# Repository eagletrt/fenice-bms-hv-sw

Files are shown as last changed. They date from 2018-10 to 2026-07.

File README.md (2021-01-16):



# Fenice's High Voltage Battery Management System

This branch contains two projects: mainboard and cellboard.

For guidelines on how this branching system works head over to the [master's branch README](https://github.com/eagletrt/fenice-bms-hv/blob/master/README.md#repo-guidlines).

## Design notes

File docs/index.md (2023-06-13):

# High-Voltage Battery Management System

Battery management is a collection of operations that ensures the safety and efficiency of the battery pack. A basic battery management system should constantly measure cell temperatures and voltages along with the total pack current output and check that each of those values is within specification.\
If anomalies are detected, the battery should be disconnected immediately via the AIRs.
A good battery management system is also able to keep the battery in good operating conditions, with the goal of maintaining the expected efficiency of the powertrain.

The need of collecting a lot of data from all over the pack has dictated a scattered architecture for the BMS: it uses multiple data acquisition boards (cellboards) and a single control board (mainboard).

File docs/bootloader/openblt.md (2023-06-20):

# OpenBLT

[OpenBLT](https://www.feaser.com/openblt/doku.php) is an open source bootloader that can run on any microcontroller and use any type of communication interface to perform **software updates**, without the need of specialized debugger hardware

Both cellboards' and mainboard's bootloaders are derived from [OpenBLT sources](https://github.com/feaser/openblt)

## Mainboard and Cellboard bootloaders

The `openblt_mainboard` and `openblt_cellboard` folders contains the actual code of the bootloader which has to be flashed to the microcontroller in order to be able to load your program via the desired communication protocol

Each project is generated by `STM32CubeMX` except the `BLT` folder which containts all the necessary sources of OpenBLT, that can be found in it's github repository either in the `Target/Source`, `Target/Source/_template` or `Target/Demo/_template/Boot` folders

The whole bootloader configuration happens in the `blt_conf.h` header file, exception made for the `flashLayout[]` variable in `flash.c`, where the flash layout is specified

---

## Flash via CAN procedure

### Building and flashing the bootloader

Being an `STM32CubeMX` projects, building and flashing the bootloader is straightforward.

### Building the firmware

In order to operate with the bootloader you need to **modify the linker file** (`*_FLASH.ld` in the root directory of your project)

In particular you need to change the `FLASH (rx)` line in the `MEMORY` segment:
   - Change the origin address according to what has been specified in the previously mentioned `flash.c` file (eg. `ORIGIN = 0x8004000`)
   - Change the length of the flash memory in order to match with the specified address (eg. `LENGTH = 496K`)

### Preparing the binaries

In order to send the binaries via CAN they have to be converted to the `.srec` format

This can be achieved with this tool: [arkku/srec](https://github.com/arkku/srec)

*Example*:
```bash
bin2srec -a 0x8004000 -i *.bin -o *.srec
```
---

### Flashing the firmware

The last step requires:
1. A device **directly connected** to the CAN, like telemetry's and steering wheel's Raspberries
2. [Can-utils](https://elinux.org/Can-utils) installed in the device
3. [Bootcommander](https://www.feaser.com/openblt/doku.php?id=manual:bootcommander) installed in the device

When everything is ready the project can be flashed by resetting the microcontroller (via an appropriate *CAN message*)
and then sending the program to flash using the **bootcommander** tool, with:
- The `-t` flag set to `xcp_can`
- The selected CAN peripheral (`-d` flag)
- The *baud rate* (`-b` flag)
- The transmission ID (`-tid` flag) and the reception ID (`-rid` flag)
- The **binary executable** converted to the `.srec` format

*Example*:
```bash
cansend can1 005#00 &&
bootcommander -t=xcp_can -d=can1 -b=1000000 -tid=667 -rid=7E1 fenice-bms.srec
```

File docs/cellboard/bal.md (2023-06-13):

# Cell Balancing
The cell balancing operation is mostly done on the cellboards. However, the mainboard has to compute all the cells that need to be discharged. To synchronize cellboards and the mainboard an FSM is defined:

```diagram
stateDiagram-v2
    direction LR
    [*] --> OFF
    OFF --> CMP
    OFF --> OFF
    CMP --> DSC
    CMP --> OFF
    DSC --> COOL
    DSC --> OFF
    DSC --> DSC
    COOL --> CMP
    COOL--> OFF
    COOL --> COOL
```
### - Off (OFF)
The dormant state of the balancing algorithm.

### - Compute (CMP)
Compute phase. This is where the cell selection algorithm is run. If no cells need to be discharged the FSM returns back to the _Off_ state.
The compute phase can be triggered manually via the CLI.

The algorithm is split in two phases:
#### Imbalance computation
The imbalance is the voltage difference between a given cell and the minimum-voltage cell. In this phase an imbalance array that contains the imbalances of every cell is created. In this case the imbalance is centered around the minimum-voltage plus a threshold, that is the maximum imbalance permitted in the pack.

$imbalance[i] = \max(0, voltages[i] −(min\_voltage + threshold))$

#### Cell selection
The cell selection algorithm is very simple: if the imbalance is greater than 0, the cell is selected for discharge

### - Discharge (DSC)
After compute the mainboard sends the list of cells to be discharged to the cellboards that start the actual discharge for a set amount of time. The discharge time depends on configuration but it's in the range from 30 to 120s.

### - Cooldown (COOL)
Cooldown. A small period (5-10s) where voltages are

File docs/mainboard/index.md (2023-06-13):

# Mainboard

**The Mainboard is the central control unit of the BMS**.\
It contains a microcontroller that handles two CAN-bus lines for internal and external communications, peripherals such as insulated *ADCs*, *EEPROMs*, serial ports, an SD-card and more.\
The mainboard is **responsible for the actuation of the AIRs and contains the shutdown and pre-charge circuits**.\
It also communicates voltages, temperatures, currents, battery status, warnings and errors to the rest of the car via CAN-bus. An integrated serial command-line interface and internal logging are included to help with troubleshooting.

The logic of the mainboard is handled by a couple of FSM *<small>(Finite States Machines)</small>*. The [FSM](https://github.com/eagletrt/micro-libs/tree/master/fsm) library is used to manage every state machine of the *BMS*.

---

## Subsystems

There are several subsystems to the mainboard's firmware:

- **[bal](subsystems/bal)**: contains functions of the cell balancing algorithm.
- **[bal_fsm](subsystems/bal)**: contains the balancing algorithm's FSM.
- **[bms_fsm](subsystems/bms_fsm)**: the BMS' FSM handles the main state machine of the board and it's responsible for the management of the tractive system's activation and deactivation.
- **[cli_bms](subsystems/cli_bms)**: all the CLI commands are defined here.
- **[config](subsystems/config)**: generic interface that handles all sorts of configurations.
- **[current](subsystems/current)**: current measurement functions.
- **[energy](subsystems/energy)**: energy measurement and State-of-Charge estimation logic.
- **[feedback](subsystems/feedback)**: mainboard's feedbacks handler functions and variables.
- **[pack](subsystems/pack)**: battery pack hardware control's interface.
- **[soc](subsystems/soc)**: State-of-Charge estimation functions *(at the moment it doesn't work)*.
- **[timebase](subsystems/timebase)**: controls all repeating actions of the firmware.

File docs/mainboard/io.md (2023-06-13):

# I/O

There are many peripherals and devices connected to the mainboard.

Every component that interfaces with the mainboard's microcontroller is listed here:

- **CAN-buses** (CAN):\
    a CAN-bus to communicate with the car and an internal isolated bus for handling the cellboards.
- **adc124021 ADC** (SPI):\
    used to measure pack's and bus' voltages, also used to measure the pack's current using a shunt resistor.
- **DAHB S/160 Hall-effect sensor** (ADC):\
    used to measure pack's current. It's less precise than the shunt, included for historical reasons. The unit contains two sensors with different gains to have a broader current range.
- **AIR and pre-charge controls**:\
    three output pins control the actuation of the AIRs *(if the shutdown circuit is not latched in the off state)* and the pre-charge circuit.
- **Circuit feedbacks** (MUX/ADC):\
    16 multiplexed analog signals coming from the mainboard's circuit. It's used to diagnose the circuit and to verify its correct state compared to the BMS state. Some of those feedbacks are not multiplexed to let them generate of interrupts.
- **IMD Status** (PWM):\
    the IMD has an output PWM signal that reports its internal state.
- **M95256 EEPROM** (SPI):\
    used to store runtime variables and data, such as State-of-Charge information, balancing threshold and more.
- **SD-card** (SPI):\
    an SD-card has been included on the mainboard, in order to use it as storage for extended logs.
- **User console** (UART):\
    a serial interface has been reserved as an user interface to read/write data and execute commands. The [cli](https://github.com/eagletrt/micro-libs/tree/master/cli) library is used as an interface.
- **GPIOs**:\
    9 GPIO pins for external stuff.

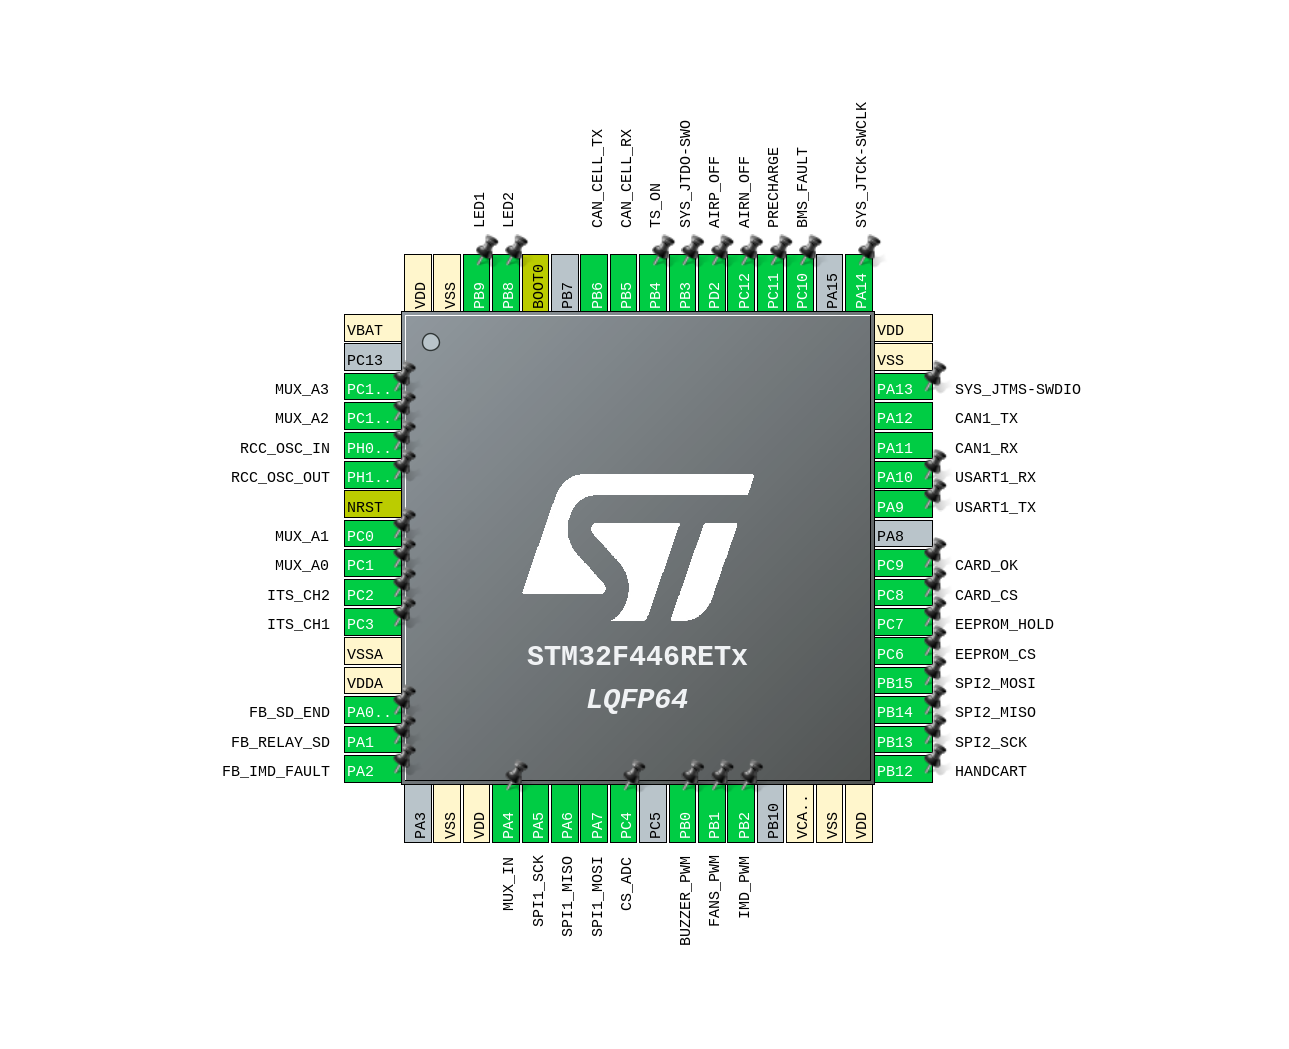
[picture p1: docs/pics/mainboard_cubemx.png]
Mainboard's I/O configuration


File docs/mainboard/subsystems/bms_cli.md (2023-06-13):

# Command Line Interface

The command line interface of the Mainboard is based on the [cli](https://github.com/eagletrt/micro-libs/tree/master/cli) library. It serves as the main interface with the BMS. The CLI is clocked at 115200 baud and uses local echo

!!! warning
	The CLI runs on UART1, thus it is not compatible with STM32 Nucleo boards that normally use UART2 as the USB serial console.

As the name implies, the CLI is based around commands, in a style inspired by Unix consoles. Pressing `?` followed by `Enter` will give a list of legal commands.

## Commands
### `volt`
The `volt` command returns the main voltages of the battery pack.

!!! example
	```
	bus.......0.00 V
	internal..388.8 V
	average...3.60 V
	max.......3.70 V
	min.......3.50 V
	delta.....0.20 V
	```

#### Parameters
- `all`: prints all cell voltages (plus some usefull information about balancing).

### `temp`
Similarly to the `volt` command, `temp` will return the main temperatures of the pack.
#### Parameters
- `all`: Prints all battery temperatures.

### `status`
Returns a summary of the general status of the BMS.

### `errors`
This command will return a list containing each active errors and its details

### `ts`
Controls the Tractive System actuation.
#### Parameters
- `on`: generates a `TS_ON` event on the [BMS FSM](../bms_fsm).
- `off`: triggers `TS_OFF` event on the aforementioned FSM.

### `bal`
Suite of commands that handle the balancing process.
#### Parameters
- `on`: Triggers an event that enables the [BAL FSM](../bal_fsm).
- `off`: Triggers an event that disables balancing.
- `thr`: Returns the currently set threshold.
- `thr <millivolts>`: Sets the threshold to the value of `<millivolts>`.
    Please be gentle with it: it can break bad if you input strange stuff
- `test <board> <cell0 cell1 ... cellN>`: starts a balancing cycle in the `board` on the specified cells

### `soc`
Return state of charge information
#### Parameters
- `reset`: resets the 'last charge' energy meter.

### `current`
Shows current measurement for all the available sensors.
#### Parameters
- `zero`: zeroes the Hall-effect sensors.

### `dmesg`
Toggles the debug output. This can be quite verbose if enabled.

### `reset`
Resets the microcontroller. Analogue to pressing the reset button on board.

### `imd`
Show imd details

### `feedbacks`
Show feedbacks status

### `watch`
Repeatedly run a command
#### Parameters
- `<interval ms> <cmd>`

### `cell_distr`
Lets you change the cellboard arrangment into the pork
#### Parameters
- ``: Show current cellboard distribution
- `<cell0> ... <cellN>`: Update cellboard distribution

### `fans`
Control the pork fans
#### Parameters
- `off`: shut down fans
- `<0-100>`: sets fans power

### `pack`
Control low level ts hardware
!!! warning
	This can lead to dangerous behaviours when the tractive system is connected, be carefull
#### Parameters
- `airn <on/off>`: controls the air negative
- `airp <on/off>`: controls the air positive
- `precharge <on/off>`: controls the precharge relay

### Easter eggs?
Of course

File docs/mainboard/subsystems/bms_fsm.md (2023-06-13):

# Main State Machine
The BMS fsm handles the main state machine of the board. It is responsible for the management of the tractive system activation and deactivation.

# States
```diagram
stateDiagram-v2
    direction LR
    [*] --> Idle
    Idle --> AirnClose
    Idle --> Error
    AirnClose --> Idle
    AirnClose --> AirnStatus
    AirnClose --> Error
    AirnStatus --> Precharge
    AirnStatus --> Idle
    AirnStatus --> Error
    Precharge --> On
    Precharge --> Idle
    Precharge --> Error
    On --> Idle
    On --> Error
    Error --> Idle
```

## - **Idle**
When the TS is off and no fatal errors are present, the BMS is in the Idle state.

## - **AirnClose**
When the procedure of activation of the Tractive System is requested. Additional feedbacks are checked in order to close the AIR negative.

## - **AirnStatus**
Checks if the activation of the AIR negative is ok.

## - **Precharge**
The Precharge procedure is done to turn on the Tractive System. It involves the actuation of the precharge relay and the monitoring of the bus voltage.
The bus voltage is periodically confronted with the internal voltage and when they are within 7% of each other the positive AIR is closed and the precharge relay is opened, ending the precharge procedure. The FSM then transitions to the TS_On state. If the bus voltage doesn't rise fast enough, the precharge fails and the FSM goes back to Idle.

## - **TS_On**
In this state the high-voltage bus external to the battery is powered. This is the state in which the car can run, or the battery can be charged.
When the TS_OFF event occurs, the FSM transitions back to Idle, opening both AIRs at the same time.

## - **Error**
If a fatal error is active the BMS is in this state. TS activation requests are ignored. If every fatal error expires, then the BMS returns to Idle and can accept TS on commands again.

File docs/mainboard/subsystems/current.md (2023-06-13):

# Current
Current measurements involves 2 different sensors, the shunt resistor, measured through the isolated ADC and the 2-channel analog Hall sensor, sampled through internal ADCs.

### Current zeroing
All the 3 measures involve offsets, which are calculated in those situations where the current is 0 (when both AIRs and precharge relay are open).

### Shunt resistor
The value coming from the ADC is converted with this formula: `(volt - shunt_offset) / (1e-4f * 500)`

### Hall Sensor
#### High channel
The analog signal is read by adc2 in DMA mode in a 128 items array. When the current need to be retrieved, those values are averaged. The value is converted with this formula: `(499.f / 300.f / 6.67e-3f) * (volt - high_channel_offset)`

#### Low channel
The analog signal is read by adc3 in DMA mode in a 128 items array. When the current need to be retrieved, those values are averaged. The value is converted with this formula: `(499.f / 300.f / 40e-3f) * (volt - low_channel_offset)`

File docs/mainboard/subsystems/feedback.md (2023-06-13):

# Feedback
Feedback system is a self check of the car state, used in the [bms_fsm](subsystems/bms_fsm).  
It consists of 19 signals by which is possible to verify the correct behaviour of the fsm and react to changes on the shutdown.
16 of them are multiplexed and 3 are not, in order to react quicker to them.
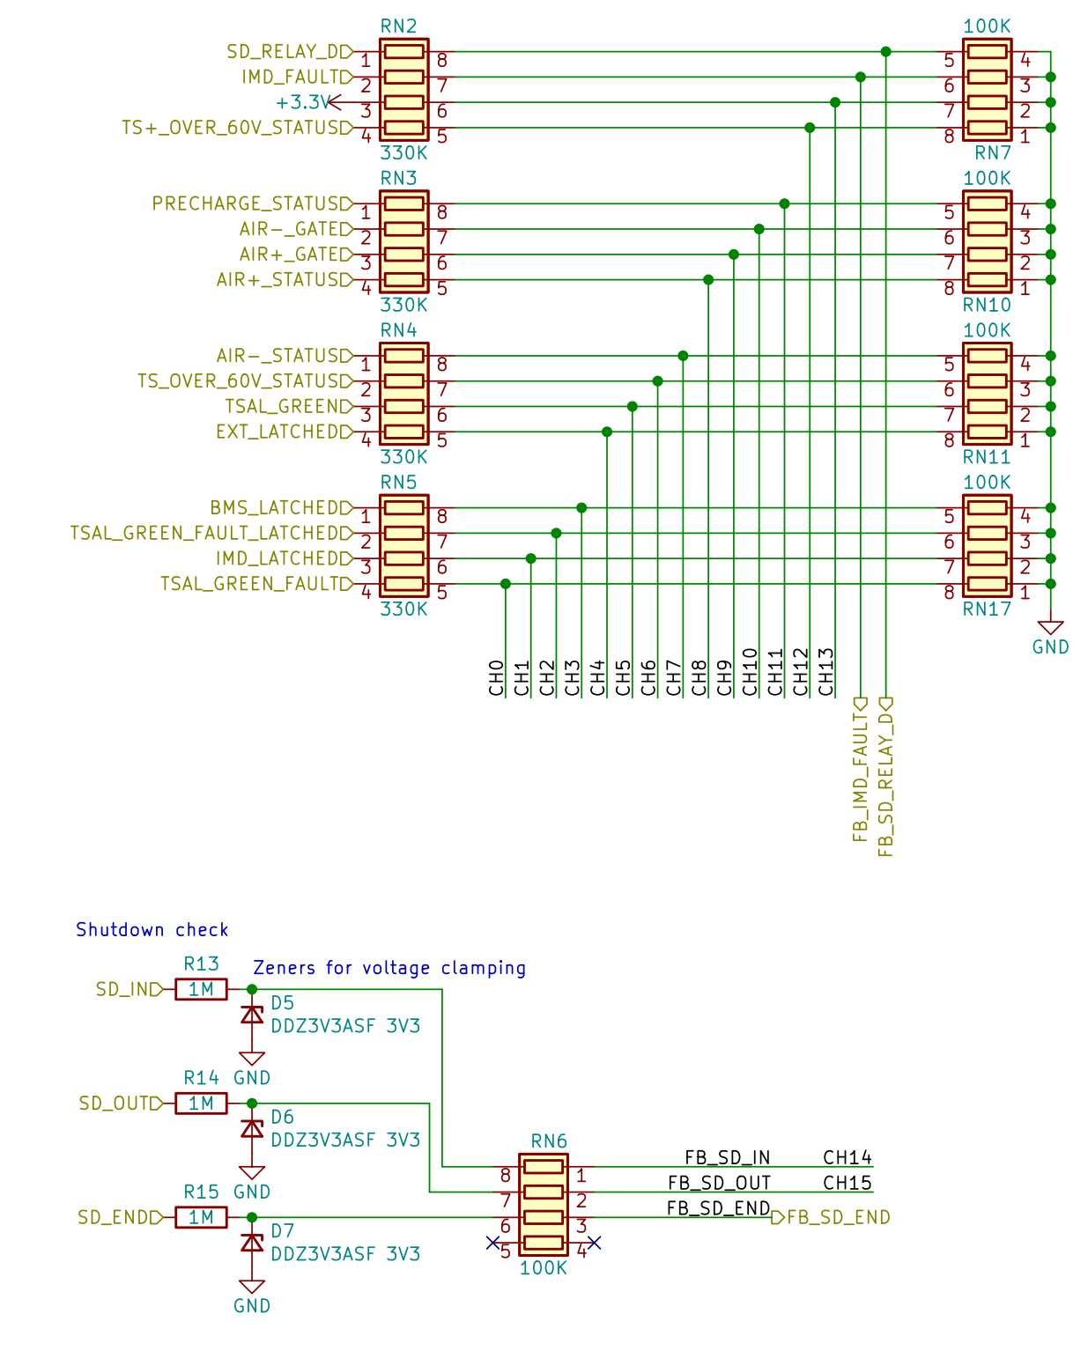
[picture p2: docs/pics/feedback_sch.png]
bms_fsm

All theese signals are read with an internal ADC (adc1) in order to better interprete their logic state (actually if <2.5V is low, >9.5 is high and everything in between is unsafe)

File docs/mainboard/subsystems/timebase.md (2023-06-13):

# Timebase
It sets a timer to tick every 10ms, then sets the respective flag whenever a interval is matched. By calling it's routine function from the main loop is possible to execute the needed code at fixed intervals.
Specifically is used to read voltages, current and temperatures, to send periodic can messages and to control fans.

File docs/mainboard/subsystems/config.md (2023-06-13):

# Config
The config subsystem is a generic configuration manager that handles the storage and retrieval of vairables from an on-board EEPROM, model m95256.
The `config` struct contains all the needed data:
```c
struct config {
    uint32_t version;
    uint16_t address;
    bool dirty;
    size_t size;
    void *data;
};
```
`version` stores a version string that is used during to verify that the read data is right. By changing the version string the data gets automatically overwritten with default values.

The `config` struct is rendered opaque by the use of the `config_t` type. This avoids direct access to `config`'s content.

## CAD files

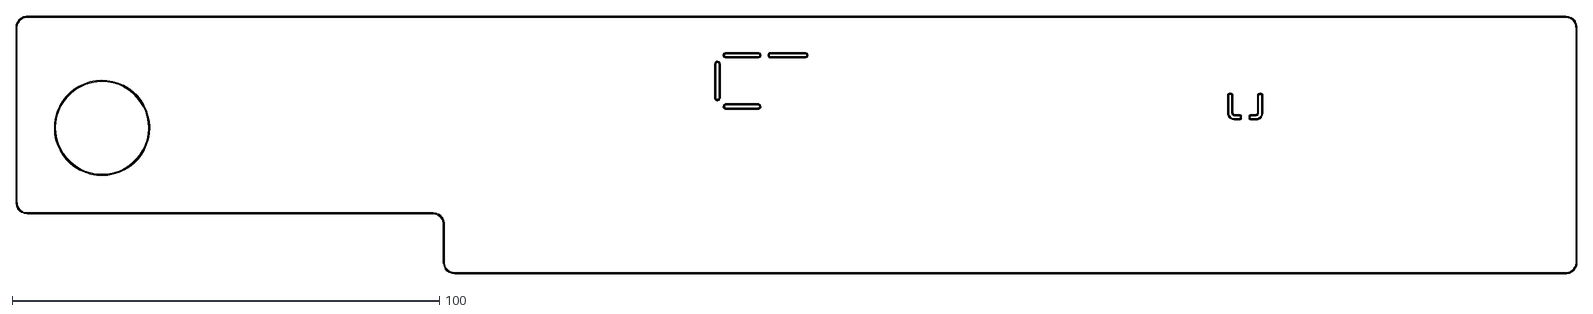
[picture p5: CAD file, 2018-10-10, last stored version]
Schematics/BMS_HV-2017-2018 chimera/BMS_HV/MainBoard/V2/gerber/MainBoard-Edge.Cuts.dxf
365.2 x 60.2

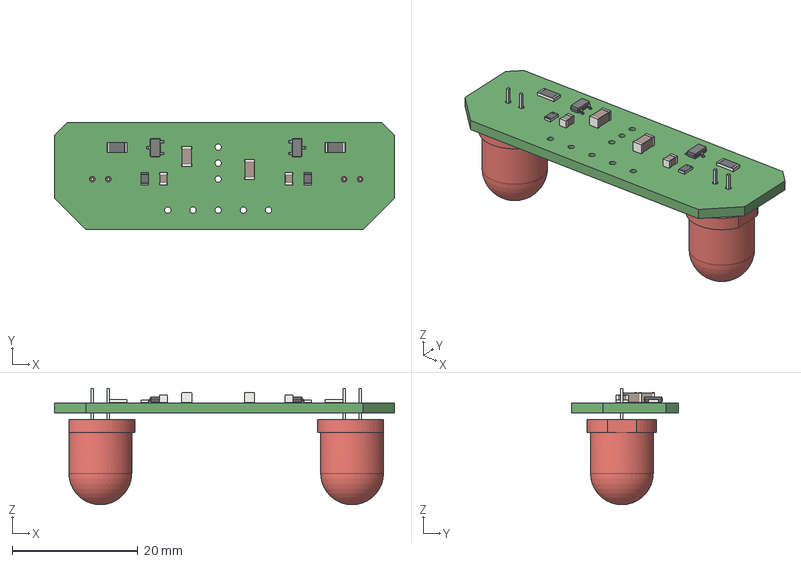
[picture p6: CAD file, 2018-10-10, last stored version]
Schematics/BMS_HV-2017-2018 chimera/BMS_HV/CockpitLED/CockpitLED.stp
54.0 x 17.0 x 18.5 mm

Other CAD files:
Schematics/BMS_HV-2017-2018 chimera/BMS_HV/CockpitLED/Box.ipt
Schematics/BMS_HV-2017-2018 chimera/BMS_HV/CockpitLED/COMPOUND.ipt
Schematics/BMS_HV-2017-2018 chimera/BMS_HV/CockpitLED/C_0805_2012Metric.iam
Schematics/BMS_HV-2017-2018 chimera/BMS_HV/CockpitLED/C_1206_3216Metric.iam
Schematics/BMS_HV-2017-2018 chimera/BMS_HV/CockpitLED/CockpitLED.iam
Schematics/BMS_HV-2017-2018 chimera/BMS_HV/CockpitLED/LED_D10.0mm.iam
Schematics/BMS_HV-2017-2018 chimera/BMS_HV/CockpitLED/OldVersions/Box.0002.ipt
Schematics/BMS_HV-2017-2018 chimera/BMS_HV/CockpitLED/R_0805_2012Metric.iam
Schematics/BMS_HV-2017-2018 chimera/BMS_HV/CockpitLED/R_1206_3216Metric.iam
Schematics/BMS_HV-2017-2018 chimera/BMS_HV/CockpitLED/SOLID.ipt
Schematics/BMS_HV-2017-2018 chimera/BMS_HV/CockpitLED/SOLID_1.ipt
Schematics/BMS_HV-2017-2018 chimera/BMS_HV/CockpitLED/SOLID_2.ipt
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

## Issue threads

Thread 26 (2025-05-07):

Update canlib version

Tonidotpy, 2025-05-07:
# Description

Given the last days problems with the new high voltage battery pack it is needed to put the old battery pack into the car and make it work with the latest versions of the canlib.

## Implementation Steps

1. Pull the latest version of the canlib for both mainboard and cellboard
2. Try to compile both mainboard and cellboard code and see if there is any error
3. Fix errors related to the new version of the canlib

## Additional Notes

All the messages are handled inside the `can_comm.h` file.

Closed 2025-07-02.

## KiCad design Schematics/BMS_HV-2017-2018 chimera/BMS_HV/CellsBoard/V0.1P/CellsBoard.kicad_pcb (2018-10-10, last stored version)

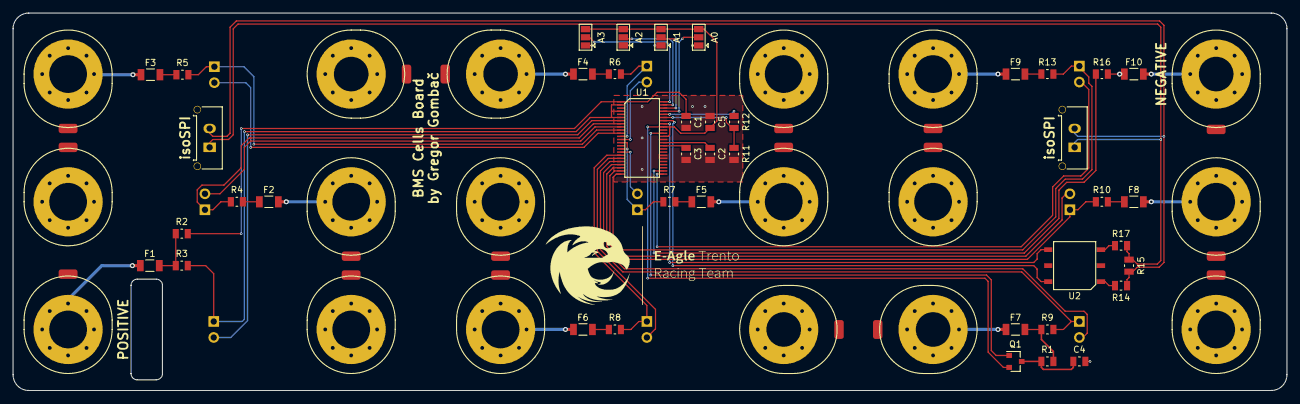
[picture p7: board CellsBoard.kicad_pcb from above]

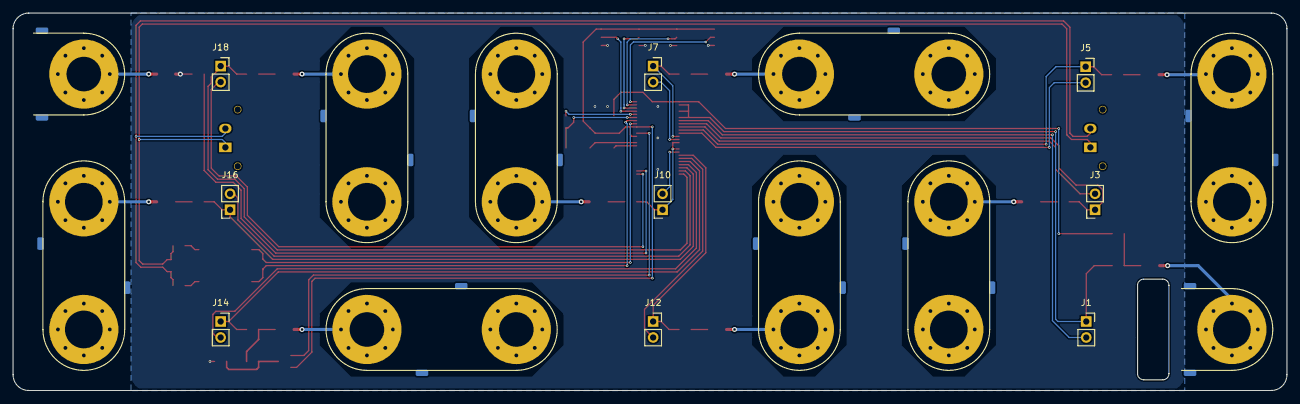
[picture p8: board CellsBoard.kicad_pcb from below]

Board: 2 copper layers, 202.5 x 60.0 mm, 60 parts (9 on the bottom side), 57 nets.

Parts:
C1, C4, C5: 100n; C_0805_2012Metric
C2, C3: 1u; C_0805_2012Metric
F1, F2, F3, F4, F5, F6, F7, F8, F9, F10: Fuse; Fuse_1206_3216Metric
J1: Temp9; PinSocket_1x02_P2.54mm_Vertical
J2: Cell9; CellEndS
J3: Temp8; PinSocket_1x02_P2.54mm_Vertical
J4: Cell8; CellShort
J5: Temp7; PinSocket_1x02_P2.54mm_Vertical
J6: Cell7; CellShort
J7: Temp6; PinSocket_1x02_P2.54mm_Vertical
J8: Cell6; CellLong
J10: Temp5; PinSocket_1x02_P2.54mm_Vertical
J11: Cell5; CellShort
J12: Temp4; PinSocket_1x02_P2.54mm_Vertical
J13: Cell4; CellShort
J14: Temp3; PinSocket_1x02_P2.54mm_Vertical
J15: Cell3; CellLong
J16: Temp2; PinSocket_1x02_P2.54mm_Vertical
J17: Cell2; CellShort
J18: Temp1; PinSocket_1x02_P2.54mm_Vertical
J19: Cell1; CellShort
J20: Cell0; CellEndD
J21, J22: isoSPI; Molex_Micro-Fit_3.0_43650-0215_1x02_P3.00mm_Vertical
JP1: A3; SolderJumper-3_P1.3mm_Open_Pad1.0x1.5mm
JP2: A2; SolderJumper-3_P1.3mm_Open_Pad1.0x1.5mm
JP3: A1; SolderJumper-3_P1.3mm_Open_Pad1.0x1.5mm
JP4: A0; SolderJumper-3_P1.3mm_Open_Pad1.0x1.5mm
Q1: BC846AW; SOT-23
R1, R2: 100R; R_0805_2012Metric
R3, R4, R5, R6, R7, R8, R9, R10, R13, R16: 330R; R_0805_2012Metric
R11: 1K4; R_0805_2012Metric
R12: 604R; R_0805_2012Metric
R14, R17: 22R; R_0805_2012Metric
R15: 120R; R_0805_2012Metric
U1: LTC6804; SSOP-48
U2: HM2103

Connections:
/0V: C1.2, C2.2, C3.2, C4.2, C5.2, F10.2, JP1.1, JP2.1, JP3.1, JP4.1, R11.2, R16.1, U1.30, U1.31, U1.36
/A0: JP4.2, U1.45
/A1: JP3.2, U1.46
/A2: JP2.2, U1.47
/A3: JP1.2, U1.48
/C0: R16.2, U1.26
/C1: J18.1, R13.2, U1.24
/C2: J16.1, R10.2, U1.22
/C3: J14.1, R9.2, U1.20
/C4: J12.1, R8.2, U1.18
/C5: J10.1, R7.2, U1.14, U1.16
/C6: J7.1, R6.2, U1.12
/C7: J5.1, R5.2, U1.10
/C8: J3.1, R4.2, U1.8
/C9: J1.1, R3.2, U1.2, U1.4, U1.6
/CB1: F9.2, R13.1
/CB2: F8.2, R10.1
/CB3: F7.2, R1.1, R9.1
/CB4: F6.2, R8.1
/CB5: F5.2, R7.1
/CB6: F4.2, R6.1
/CB7: F3.2, R5.1
/CB8: F2.2, R4.1
/CB9: F1.2, R2.1, R3.1
/S1: J18.2, U1.25
/S2: J16.2, U1.23
/S3: J14.2, U1.21
/S4: J12.2, U1.19
/S5: J10.2, U1.17
/S6: J7.2, U1.13
/S7: J5.2, U1.11
/S8: J3.2, U1.9
/S9: J1.2, U1.7
/V+: C1.1, R2.2, U1.1
/VRef1: C2.1, U1.35
/VRef2: C3.1, U1.34
/Vreg: C5.1, JP1.3, JP2.3, JP3.3, JP4.3, Q1.2, U1.37, U1.40
/drive: Q1.1, U1.38
unnamed: C4.1, Q1.3, R1.2
unnamed: F1.1, J2.1
unnamed: F2.1, J4.1
unnamed: F3.1, J6.1
unnamed: F4.1, J8.1
unnamed: F5.1, J11.1
unnamed: F6.1, J13.1
unnamed: F7.1, J15.1
unnamed: F8.1, J17.1
unnamed: F9.1, J19.1
unnamed: F10.1, J20.1
unnamed: J21.1, J22.1, R15.2, R17.2
unnamed: J21.2, J22.2, R14.2, R15.1
unnamed: R11.1, R12.2, U1.43
unnamed: R12.1, U1.44
unnamed: R14.1, U2.1
unnamed: R17.1, U2.3
unnamed: U1.41, U2.4
unnamed: U1.42, U2.6

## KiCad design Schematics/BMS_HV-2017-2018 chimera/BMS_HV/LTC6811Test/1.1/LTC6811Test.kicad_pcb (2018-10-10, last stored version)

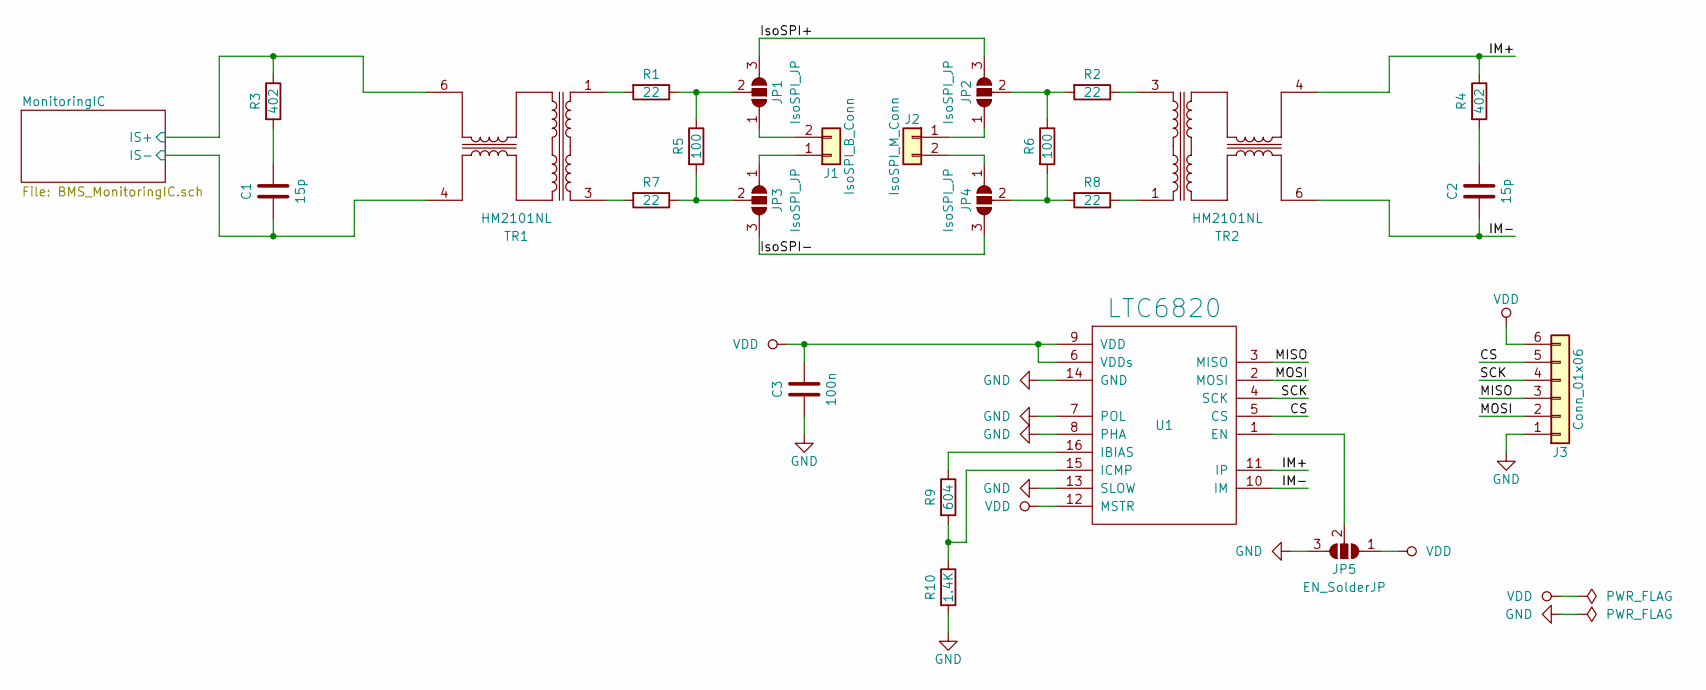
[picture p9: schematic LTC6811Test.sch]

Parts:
C1, C2: 15p; C_0805_2012Metric_Pad1.15x1.50mm_HandSolder
C3: 100n; C_0805_2012Metric_Pad1.15x1.50mm_HandSolder
J1: IsoSPI_B_Conn; PinHeader_1x02_P2.54mm_Vertical
J2: IsoSPI_M_Conn; PinHeader_1x02_P2.54mm_Vertical
J3: Conn_01x06; PinHeader_1x06_P2.54mm_Vertical
JP1, JP2, JP3, JP4: IsoSPI_JP; SolderJumper-3_P1.3mm_Open_Pad1.0x1.5mm
JP5: EN_SolderJP; SolderJumper-3_P1.3mm_Open_Pad1.0x1.5mm
R1, R2, R7, R8: 22; R_0805_2012Metric_Pad1.15x1.50mm_HandSolder
R3, R4: 402; R_0805_2012Metric_Pad1.15x1.50mm_HandSolder
R5, R6: 100; R_0805_2012Metric_Pad1.15x1.50mm_HandSolder
R9: 604; R_0805_2012Metric_Pad1.15x1.50mm_HandSolder
R10: 1.4K; R_0805_2012Metric_Pad1.15x1.50mm_HandSolder
TR1, TR2: HM2101NL
U1: LTC6820; MSOP-16

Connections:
/CS: J3.5, U1.5 (CS)
/IM+: R4.1, TR2.4, U1.11 (IP)
/IM-: C2.1, TR2.6, U1.10 (IM)
/IsoSPI+: JP1.3 (B), JP2.3 (B)
/IsoSPI-: JP3.3 (B), JP4.3 (B)
/MISO: J3.3, U1.3 (MISO)
/MOSI: J3.2, U1.2 (MOSI)
/MonitoringIC/IS+: R3.1, TR1.6; also elsewhere on the board
/MonitoringIC/IS-: C1.1, TR1.4; also elsewhere on the board
/SCK: J3.4, U1.4 (SCK)
GND: C3.2, J3.1, JP5.3 (B), R10.2, U1.7 (POL), U1.8 (PHA), U1.13 (SLOW), U1.14 (GND)
unnamed: C1.2, R3.2
unnamed: C2.2, R4.2
unnamed: J1.1, JP3.1 (A)
unnamed: J1.2, JP1.1 (A)
unnamed: J2.1, JP2.1 (A)
unnamed: J2.2, JP4.1 (A)
unnamed: JP1.2 (C), R1.1, R5.1
unnamed: JP2.2 (C), R2.2, R6.1
unnamed: JP3.2 (C), R5.2, R7.1
unnamed: JP4.2 (C), R6.2, R8.2
unnamed: JP5.2 (C), U1.1 (EN)
unnamed: R1.2, TR1.1
unnamed: R2.1, TR2.3
unnamed: R7.2, TR1.3
unnamed: R8.1, TR2.1
unnamed: R9.1, U1.16 (IBIAS)
unnamed: R9.2, R10.1, U1.15 (ICMP)
VDD: C3.1, J3.6, JP5.1 (A), U1.6 (VDDs), U1.9 (VDD), U1.12 (MSTR)

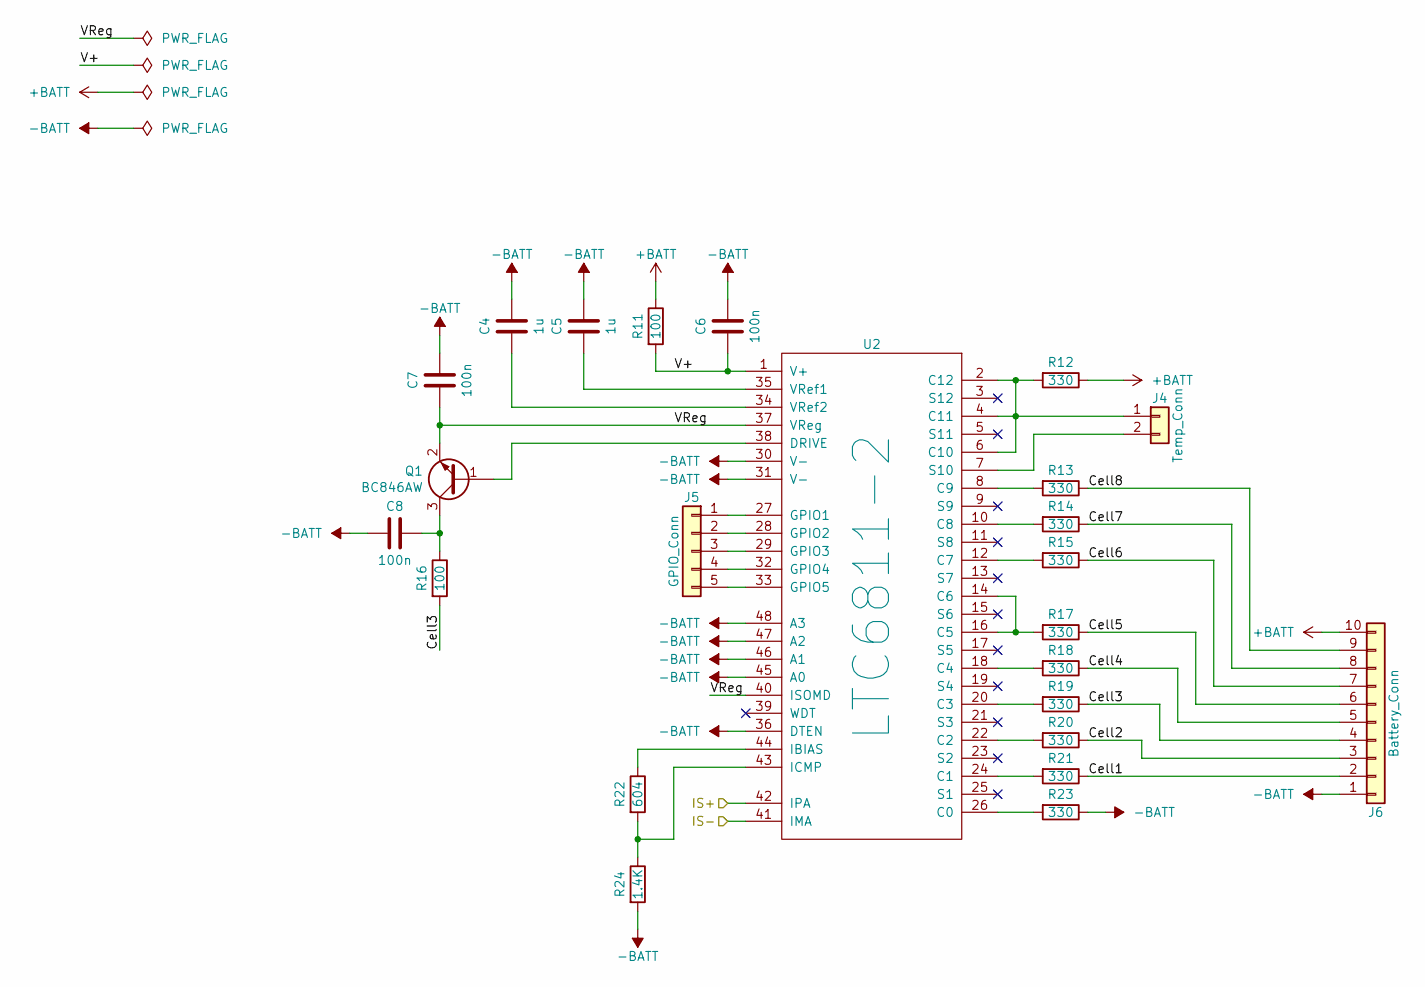
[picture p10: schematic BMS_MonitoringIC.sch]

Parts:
C4, C5: 1u; C_0805_2012Metric_Pad1.15x1.50mm_HandSolder
C6, C7, C8: 100n; C_0805_2012Metric_Pad1.15x1.50mm_HandSolder
J4: Temp_Conn; PinHeader_1x02_P2.54mm_Vertical
J5: GPIO_Conn; PinHeader_1x05_P2.54mm_Vertical
J6: Battery_Conn; PinHeader_1x10_P2.54mm_Vertical
Q1: BC846AW; SOT-323_SC-70_Handsoldering
R11, R16: 100; R_0805_2012Metric_Pad1.15x1.50mm_HandSolder
R12, R13, R14, R15, R17, R18, R19, R20, R21, R23: 330; R_0805_2012Metric_Pad1.15x1.50mm_HandSolder
R22: 604; R_0805_2012Metric_Pad1.15x1.50mm_HandSolder
R24: 1.4K; R_0805_2012Metric_Pad1.15x1.50mm_HandSolder
U2: LTC6811-2; SSOP-48

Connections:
+BATT: J6.10, R11.1, R12.1
-BATT: C4.1, C5.1, C6.1, C7.1, C8.2, J6.1, R23.1, R24.2, U2.30 (V-), U2.31 (V-), U2.36 (DTEN), U2.45 (A0), U2.46 (A1), U2.47 (A2), U2.48 (A3)
/MonitoringIC/Cell1: J6.2, R21.1
/MonitoringIC/Cell2: J6.3, R20.1
/MonitoringIC/Cell3: J6.4, R16.2, R19.1
/MonitoringIC/Cell4: J6.5, R18.1
/MonitoringIC/Cell5: J6.6, R17.1
/MonitoringIC/Cell6: J6.7, R15.1
/MonitoringIC/Cell7: J6.8, R14.1
/MonitoringIC/Cell8: J6.9, R13.1
/MonitoringIC/IS+: U2.42 (IPA); also elsewhere on the board
/MonitoringIC/IS-: U2.41 (IMA); also elsewhere on the board
/MonitoringIC/V+: C6.2, R11.2, U2.1 (V+)
/MonitoringIC/VReg: C7.2, Q1.2 (E), U2.37 (VReg), U2.40 (ISOMD)
unnamed: C4.2, U2.34 (VRef2)
unnamed: C5.2, U2.35 (VRef1)
unnamed: C8.1, Q1.3 (C), R16.1
unnamed: J4.1, R12.2, U2.2 (C12), U2.4 (C11), U2.6 (C10)
unnamed: J4.2, U2.7 (S10)
unnamed: J5.1, U2.27 (GPIO1)
unnamed: J5.2, U2.28 (GPIO2)
unnamed: J5.3, U2.29 (GPIO3)
unnamed: J5.4, U2.32 (GPIO4)
unnamed: J5.5, U2.33 (GPIO5)
unnamed: Q1.1 (B), U2.38 (DRIVE)
unnamed: R13.2, U2.8 (C9)
unnamed: R14.2, U2.10 (C8)
unnamed: R15.2, U2.12 (C7)
unnamed: R17.2, U2.14 (C6), U2.16 (C5)
unnamed: R18.2, U2.18 (C4)
unnamed: R19.2, U2.20 (C3)
unnamed: R20.2, U2.22 (C2)
unnamed: R21.2, U2.24 (C1)
unnamed: R22.1, U2.44 (IBIAS)
unnamed: R22.2, R24.1, U2.43 (ICMP)
unnamed: R23.2, U2.26 (C0)

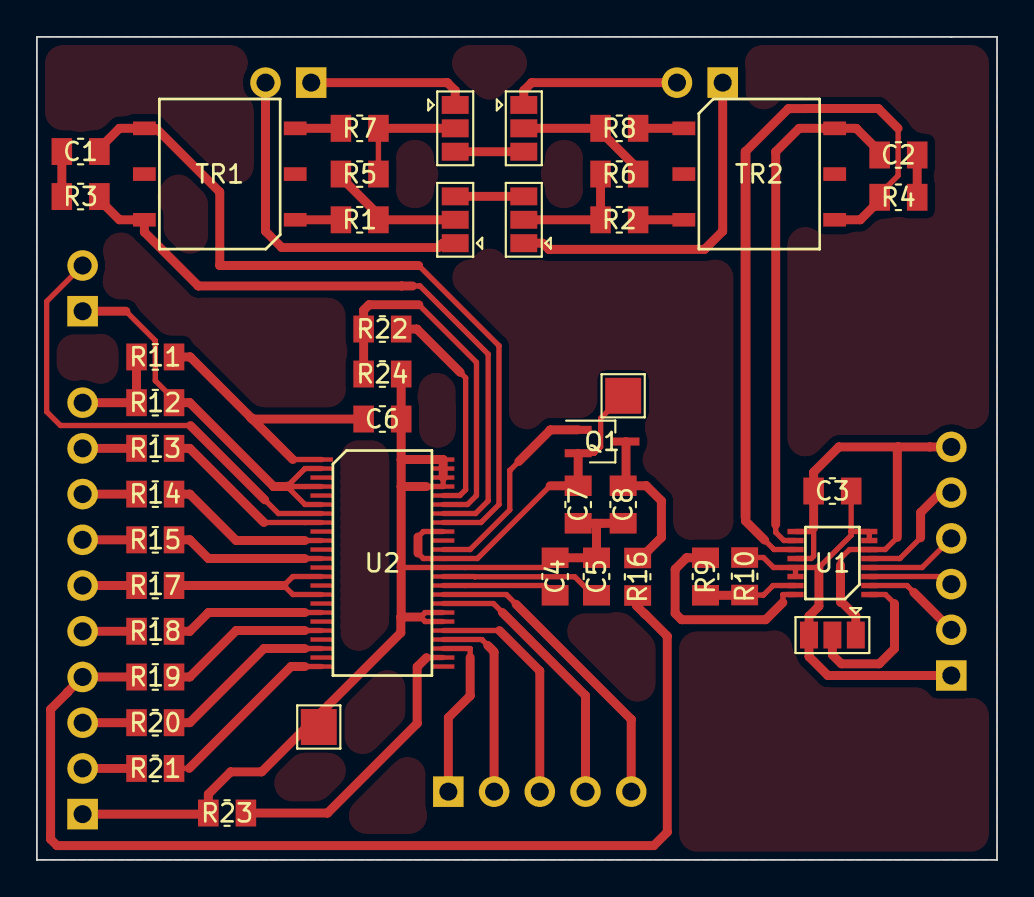
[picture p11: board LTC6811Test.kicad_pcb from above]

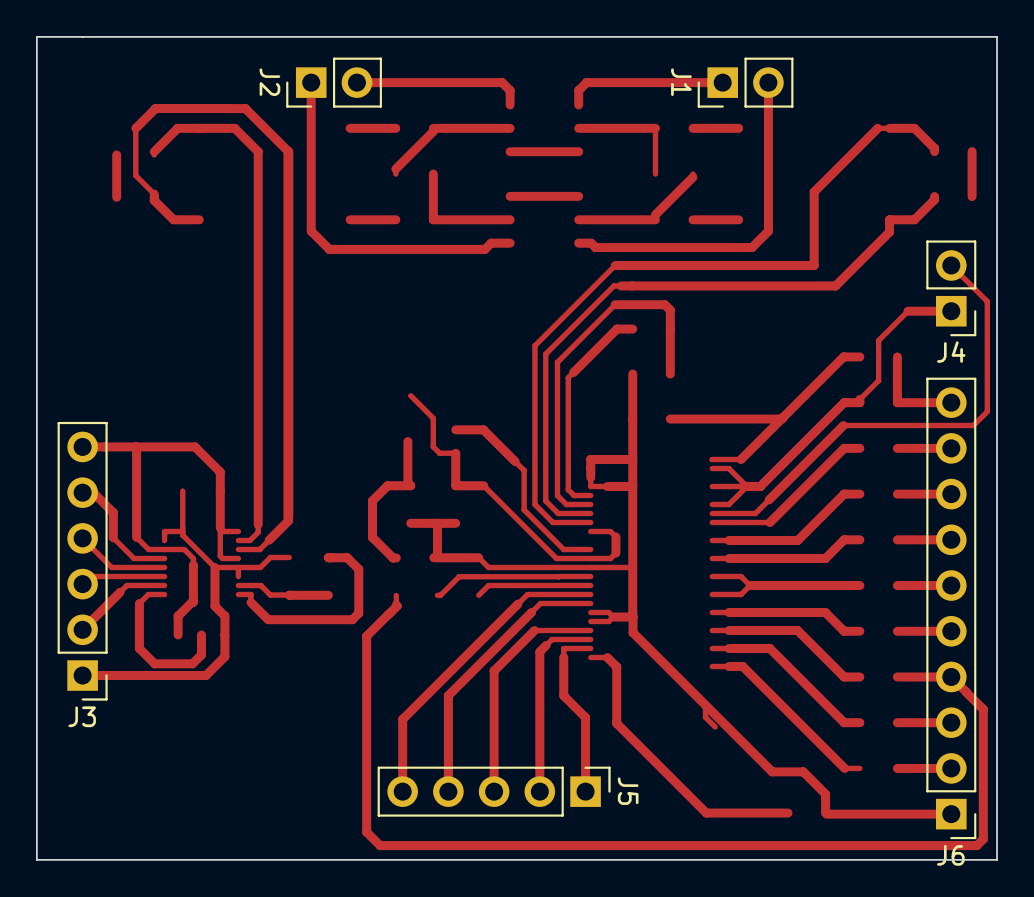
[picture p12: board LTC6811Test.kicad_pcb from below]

Board: 2 copper layers, 53.3 x 45.7 mm, 48 parts (6 on the bottom side), 63 nets.

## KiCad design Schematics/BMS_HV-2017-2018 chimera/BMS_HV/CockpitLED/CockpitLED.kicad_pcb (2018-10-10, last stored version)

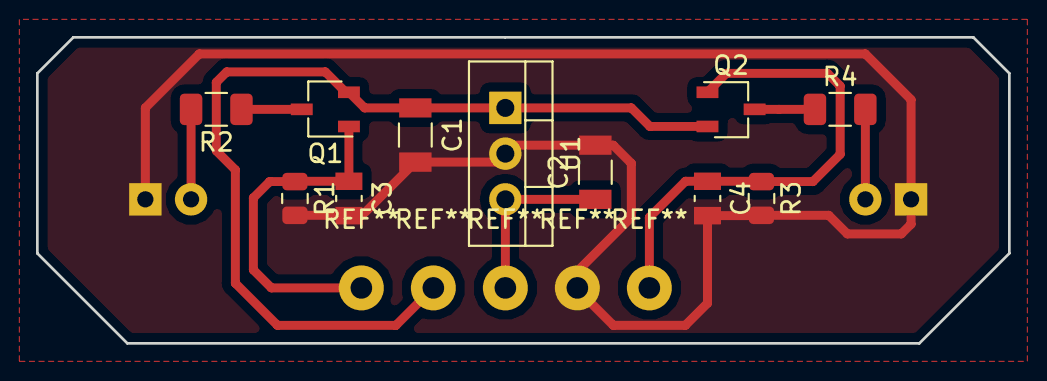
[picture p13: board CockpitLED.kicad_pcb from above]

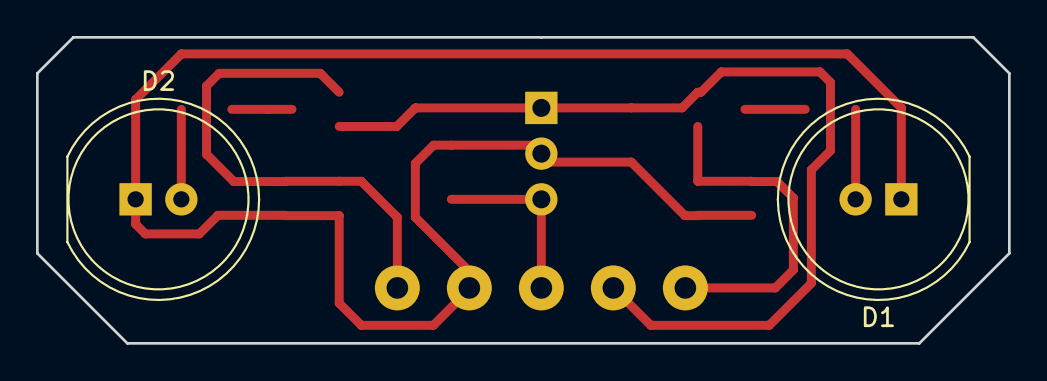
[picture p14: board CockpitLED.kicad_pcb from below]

Board: 2 copper layers, 54.0 x 17.0 mm, 13 parts (2 on the bottom side), 9 nets.

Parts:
C1: 10u; C_1206_3216Metric
C2: 22u; C_1206_3216Metric
C3, C4: 100n; C_0805_2012Metric
D1, D2: SSL-LX100133SRC/E; LED_D10.0mm
Q1, Q2: TSM3401; TSOT-23
R1, R3: 1M; R_0805_2012Metric
R2, R4: 330; R_1206_3216Metric
U1: VXO7805-500; TO-220-3_Vertical

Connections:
+5V: C2.1, U1.3
+12V: C1.1, Q1.2, Q2.2, U1.1
/BMS: C4.1, Q2.1, R3.1
/IMD: C3.1, Q1.1, R1.1
GND: C1.2, C2.2, C3.2, C4.2, D1.1, D2.1, R1.2, R3.2, U1.2
unnamed: D1.2, R2.2
unnamed: D2.2, R4.2
unnamed: Q1.3, R2.1
unnamed: Q2.3, R4.1

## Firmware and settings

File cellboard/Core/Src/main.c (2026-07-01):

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
/* Includes ------------------------------------------------------------------*/
#include "main.h"
#include "can.h"
#include "i2c.h"
#include "spi.h"
#include "tim.h"
#include "usart.h"
#include "gpio.h"

/* USER CODE BEGIN Includes */
#include "bal_fsm.h"
#include "can_comms.h"
#include "blink.h"
#include "ltc6813_utils.h"
#include "measurements.h"
#include "temp.h"
#include "volt.h"

#include <stdio.h>
#include <string.h>
/* USER CODE END Includes */


/* USER CODE BEGIN PV */

uint8_t cellboard_index = 0;
uint32_t volt_timer     = 0;
uint32_t temp_timer     = 0;

/* USER CODE END PV */

void SystemClock_Config(void);
/* USER CODE BEGIN 0 */

static void VectorBase_Config(void) {
    /* The constant array with vectors of the vector table is declared externally in the
   * c-startup code.
   */
    extern const unsigned long g_pfnVectors[];

    /* Remap the vector table to where the vector table is located for this program. */
    SCB->VTOR = (unsigned long)&g_pfnVectors[0];
}

/* USER CODE END 0 */

/**
  * @brief  The application entry point.
  * @retval int
  */
int main(void)
{
  /* USER CODE BEGIN 1 */

  VectorBase_Config();
  
  /* USER CODE END 1 */

  /* MCU Configuration--------------------------------------------------------*/

  /* Reset of all peripherals, Initializes the Flash interface and the Systick. */
  HAL_Init();

  /* Configure the system clock */
  SystemClock_Config();

  /* Initialize all configured peripherals */
  MX_GPIO_Init();
  MX_CAN1_Init();
  MX_I2C1_Init();
  MX_SPI1_Init();
  MX_SPI3_Init();
  MX_USART1_UART_Init();
  MX_TIM2_Init();
  MX_TIM15_Init();
  MX_TIM16_Init();
  /* USER CODE BEGIN 2 */

    cellboard_index = HAL_GPIO_ReadPin(ADDRESS_2_GPIO_Port, ADDRESS_2_Pin) |
                      HAL_GPIO_ReadPin(ADDRESS_1_GPIO_Port, ADDRESS_1_Pin) << 1 |
                      HAL_GPIO_ReadPin(ADDRESS_0_GPIO_Port, ADDRESS_0_Pin) << 2;

    if (cellboard_index == 7)
        cellboard_index = 5;

    volt_init();
    temp_init();

    //set temperature limits ( 0 - 60 )
    temp_set_limits(1.0, CELL_MAX_TEMPERATURE);

    can_init_with_filter();

    measurements_init(&HTIM_MEASURES);

    blink_init();
    // HAL_TIM_Base_Start_IT(&DISCHARGE_TIMER);

  /* USER CODE END 2 */

  /* Infinite loop */
  /* USER CODE BEGIN WHILE */
    while (1) {
        HAL_GPIO_WritePin(LED_GPIO_Port, LED_Pin, blink_routine(HAL_GetTick()));
        measurements_flags_check();
#ifdef UART_LOGGING
        if (HAL_GetTick() - temp_timer >= 500) {
            temp_timer = HAL_GetTick();

            char buf[500] = {'\0'};
            sprintf(buf, "[%.2f]\r\n", HAL_GetTick() / 1000.0);
            uint16_t min = volt_get_min_index();

            for (uint8_t i = 0; i < CELLBOARD_CELL_COUNT; i++) {
                sprintf(buf + strlen(buf), "%3u %-.3fV", i, (float)voltages[i] / 10000);

                if (CANLIB_BITTEST(bal.cells, i))
                    sprintf(buf + strlen(buf), " D");

                if (min == i) {
                    sprintf(buf + strlen(buf), " M");
                }
                sprintf(buf + strlen(buf), "\r\n");
                //if (i % LTC6813_REG_CELL_COUNT == 0) {
                //    sprintf(buf + strlen(buf), "\r\n");
                //}
                //sprintf(buf + strlen(buf), "[%3u %-.3f V] ", i, (float)voltages[i] / 10000);
            }
            sprintf(buf + strlen(buf), "Threshold: %d mV", BAL_MAX_VOLTAGE_THRESHOLD / 10);
            sprintf(buf + strlen(buf), "\r\nBAL: %li", fsm_get_state(bal.fsm));
            if (errors != 0) {
                sprintf(buf + strlen(buf), "\r\nERRORS: %x", errors);
            }
            sprintf(buf + strlen(buf), "\r\n\n");
            HAL_UART_Transmit_IT(&CLI_UART, (uint8_t *)buf, strlen(buf));
            //HAL_Delay(200);
            //fsm_trigger_event(bal.fsm, EV_BAL_CHECK_TIMER);
        }
#endif

        fsm_run();

    /* USER CODE END WHILE */

    /* USER CODE BEGIN 3 */
    }
  /* USER CODE END 3 */
}

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


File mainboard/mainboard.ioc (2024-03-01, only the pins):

Mcu.UserName=STM32F446RETx
PA0-WKUP.GPIO_Label=PROBING_3V3
PA0-WKUP.Signal=ADCx_IN0
PA1.GPIO_Label=FB_SD_IMD
PA1.Signal=ADCx_IN1
PA10.GPIO_Label=USART_RX
PA10.Signal=USART1_RX
PA11.GPIO_Label=CAN_CAR_RX
PA11.Signal=CAN1_RX
PA12.GPIO_Label=CAN_CAR_TX
PA12.Signal=CAN1_TX
PA13.Signal=SYS_JTMS-SWDIO
PA14.Signal=SYS_JTCK-SWCLK
PA15.GPIO_Label=ADC_INT
PA15.Signal=GPIO_Output
PA2.GPIO_Label=FB_SD_BMS
PA2.Signal=ADCx_IN2
PA3.GPIO_Label=SD_IN
PA3.Signal=ADCx_IN3
PA4.GPIO_Label=MUX_IN
PA4.Signal=ADCx_IN4
PA5.GPIO_Label=ADC_SCK
PA5.Signal=SPI1_SCK
PA6.GPIO_Label=ADC_MISO
PA6.Signal=SPI1_MISO
PA7.GPIO_Label=ADC_MOSI
PA7.Signal=SPI1_MOSI
PA8.GPIO_Label=BUZZER_PWM
PA8.Signal=S_TIM1_CH1
PA9.GPIO_Label=USART_TX
PA9.Signal=USART1_TX
PB0.GPIO_Label=SD_OUT
PB0.Signal=ADCx_IN8
PB1.GPIO_Label=FANS_PWM
PB1.Signal=TIM1_CH3N
PB10.GPIO_Label=FANS_DETECT
PB10.Signal=GPIO_Input
PB13.GPIO_Label=EEPROM_SCK
PB13.Signal=SPI2_SCK
PB14.GPIO_Label=EEPROM_MISO
PB14.Signal=SPI2_MISO
PB15.GPIO_Label=EEPROM_MOSI
PB15.Signal=SPI2_MOSI
PB2.GPIO_Label=IMD_PWM
PB2.Signal=S_TIM2_CH4
PB3.GPIO_Label=MONITOR_SCK
PB3.Signal=SPI3_SCK
PB5.GPIO_Label=CAN_CELL_RX
PB5.Signal=CAN2_RX
PB6.GPIO_Label=CAN_CELL_TX
PB6.Signal=CAN2_TX
PB7.GPIO_Label=PRECHARGE
PB7.Signal=GPIO_Output
PB8.GPIO_Label=LED2
PB8.Signal=GPIO_Output
PB9.GPIO_Label=LED1
PB9.Signal=GPIO_Output
PC0.GPIO_Label=MUX_A1
PC0.Signal=GPIO_Output
PC1.GPIO_Label=MUX_A0
PC1.Signal=GPIO_Output
PC10.GPIO_Label=BMS_FAULT
PC10.Signal=GPIO_Output
PC11.GPIO_Label=MONITOR_MISO
PC11.Signal=SPI3_MISO
PC12.GPIO_Label=MONITOR_MOSI
PC12.Signal=SPI3_MOSI
PC13.GPIO_Label=CONNS_DETECTION
PC13.Signal=GPIO_Input
PC14-OSC32_IN.GPIO_Label=MUX_A3
PC14-OSC32_IN.Signal=GPIO_Output
PC15-OSC32_OUT.GPIO_Label=MUX_A2
PC15-OSC32_OUT.Signal=GPIO_Output
PC2.GPIO_Label=ITS_CH2
PC2.Signal=ADCx_IN12
PC3.GPIO_Label=ITS_CH1
PC3.Signal=ADCx_IN13
PC4.GPIO_Label=ADC_CS
PC4.Signal=GPIO_Output
PC5.GPIO_Label=AIRN_OFF
PC5.Signal=GPIO_Output
PC6.GPIO_Label=EEPROM_CS
PC6.Signal=GPIO_Output
PC7.GPIO_Label=EEPROM_HOLD
PC7.Signal=GPIO_Output
PC8.GPIO_Label=MONITOR_EN
PC8.Signal=GPIO_Output
PC9.GPIO_Label=MONITOR_CS
PC9.Signal=GPIO_Output
PD2.GPIO_Label=AIRP_OFF
PD2.Signal=GPIO_Output
PH0-OSC_IN.Signal=RCC_OSC_IN
PH1-OSC_OUT.Signal=RCC_OSC_OUT

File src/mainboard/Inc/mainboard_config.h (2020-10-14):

/**
 * @file		mainboard_config.h
 * @brief		This file contains configuration settings for fenice's mainboard 
 *
 * @date		Oct 07, 2019
 * @author		Matteo Bonora [matteo.bonora@studenti.unitn.it]
 * @author		Simone Ruffini [simone.ruffini@tutanota.com]
 */

#ifndef MAINBOARD_CONFIG_H
#define MAINBOARD_CONFIG_H

#include <inttypes.h>

//===========================================================================
//=================================== General ===============================
//===========================================================================

#define htim_Err htim2

//===========================================================================
//=================================== LTC6813 ===============================
//===========================================================================

// Set to 1 to emulate the LTC daisy chain
#define LTC6813_EMU 0

/**
 * Number of daisy chained LTCs
 */
#define LTC6813_COUNT 1

/**
 * Number of cells a single IC controls. Refer to cell_distribution for
 * configuration
 */
#define LTC6813_CELL_COUNT 18

/**
 * Number of registers for each LTC
 */
#define LTC6813_REG_COUNT 6

/**
 * Number of cells handled by a register
 */
#define LTC6813_REG_CELL_COUNT 3

#define LTC6813_TEMP_ADDRESS 69

//===========================================================================
//================================= Temperature =============================
//===========================================================================

/**
 * Temperature measurement interval (ms)
 */
#define TEMP_READ_INTERVAL 100

/**
 * How many temperatures to average together
 */
#define TEMP_SAMPLE_COUNT 4

/**
 * How many I2C buses are used to address all the sensors
 */
#define TEMP_BUS_COUNT 1

/**
 * How many strips in each bus
 */
#define TEMP_STRIPS_PER_BUS 1
/**
 * How many sensors are on a strip
 */
#define TEMP_SENSORS_PER_STRIP 6

/**
 * How many sensors on each cellboard
 */
#define TEMP_SENSOR_COUNT (TEMP_BUS_COUNT * TEMP_STRIPS_PER_BUS * TEMP_SENSORS_PER_STRIP)

/**
 * The address pin coding for each sensor in a strip. The LSB must be changed
 * from [0-2] to differentiate between each strip.
 */
static const uint8_t TEMP_SENSOR_ADDRESS_CODING[TEMP_SENSORS_PER_STRIP] = {
	000, 100, 010, 110, 020, 120};

//===========================================================================
//================================ Pack Settings ============================
//===========================================================================

/**
 * Total number of cells in series
 */
#define PACK_CELL_COUNT (LTC6813_COUNT * LTC6813_CELL_COUNT)

/**
 * How many temperature sensors in the pack
 */
#define PACK_TEMP_COUNT (TEMP_SENSOR_COUNT * LTC6813_COUNT)

/**
 * Max current. In (A * 10)
 */
#define PACK_MAX_CURRENT 2000

/**
 * Cell's limit voltages (mV * 10)
 */
#define CELL_WARN_VOLTAGE 28000
#define CELL_MIN_VOLTAGE 25000
#define CELL_MAX_VOLTAGE 42250

/**
 * Maximum cell temperature (°C * 100)
 */
#define CELL_MAX_TEMPERATURE 6000

// @section Balancing

/**
 *  Maximum voltage delta between cells (mV * 10)
 */
#define BAL_MAX_VOLTAGE_THRESHOLD 100

/**
 *  How much does a balancing cycle last (ms)
 */
#define BAL_CYCLE_LENGTH 120000

#define PRECHARGE_TIMEOUT 10000
#define PRECHARGE_VOLTAGE_THRESHOLD 0.95

/**
 * Feedback bit set bit position
 */
enum {
	FEEDBACK_VREF_POS,
	FEEDBACK_FROM_TSMS_POS,
	FEEDBACK_TO_TSMS_POS,
	FEEDBACK_FROM_SHUTDOWN_POS,
	FEEDBACK_LATCH_IMD_POS,
	FEEDBACK_LATCH_BMS_POS,
	FEEDBACK_IMD_FAULT_POS,
	FEEDBACK_BMS_FAULT_POS,
	FEEDBACK_TSAL_HV_POS,
	FEEDBACK_AIR_POSITIVE_POS,
	FEEDBACK_AIR_NEGATIVE_POS,
	FEEDBACK_PC_END_POS,
	FEEDBACK_RELAY_LV_POS,
	FEEDBACK_IMD_SHUTDOWN_POS,
	FEEDBACK_BMS_SHUTDOWN_POS,
	FEEDBACK_TS_ON_POS,

	// do not move FEEDBACK_N
	FEEDBACK_N,
};
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

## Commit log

2018-10-10 roba di greg
    [1040310811.iam, 430451612.iam, 436500215.iam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]
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2018-11-17 initial GPIO e CELL_VOLTAGE tests
    [prova Run.cfg]
2018-11-27 ltc6813 impl
    [prova Run.cfg, teststmf3 Run.cfg]
2018-12-11 fixed read cell voltages
2018-12-18 cell_voltage&gpio_voltage optimization, remove older folder
    [teststmf3 Run.cfg]
2019-10-09 Add initial STM32F4 test
2019-10-24 Update drivers to work with LL
2019-10-24 Move stuff away from the CLI interrupt. Improve data visualization
2019-10-28 Add hardware SPI CS
2019-10-29 Revert "Add hardware SPI CS"
    This reverts commit 26aaf6f3f2c1c0c8516310e2ccadb7edd2273583.
    [main.c, main.h]
2019-10-29 Fix balancing and add cli printing from anywhere
    [fenice_config.h, main.c, main.h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]
2019-11-01 Reorganize repository structure
    [1040310811.iam, 430451612.iam, 436500215.iam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]
2019-11-11 Revert "Disable old functions"
    This reverts commit 3b719b1517120831366d5132ef675df241a37d73.
    [pack.c]
2019-11-14 Add initial i2c code
2019-11-15 Fix (hopefully) I2C communication
    [main.c, main.h, pack.c]
2019-11-18 Definitely fix I2C transmission
    [main.c, pack.c]
2019-11-19 Fix total voltage calculation
    [pack.c]
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2019-11-22 Add STM32 temperature slave code
2019-12-02 FIRST WORKING I2C COMM
2019-12-06 Fix I2C communication
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2019-12-12 Fix errors with i2c transmission
2019-12-12 Setup test temperature communication
2019-12-13 Add read all temperatures on demand
2020-01-30 Add PTC2075DP temperature sensor support
2020-02-04 Add temperature.c and reorganize fenice_config.h
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2020-02-17 Add support for si8900 uart insulated ADC measurement
2020-02-22 Fix temperature measurement
2020-03-02 Improve voltage reading support
2020-03-02 Fix voltage measurement
2020-03-11 Overhaul error management, using double linked list and reference arrays
    [main.c, pack.c]
2020-03-12 Fix temperature indexing
2020-03-12 Clean up error files
    [main.c]
2020-03-18 Add error management to si8900
    [main.c]
2020-03-21 Convert project to STM32G4
2020-03-24 Partially fix cli freezes
    [fenice_config.h, main.c]
2020-03-24 framework of FDCAN init
2020-03-27 moved fsm from main and made framework for fsm
2020-03-27 Battery pack data update: scope, type and getter/setters definition
2020-04-04 -running BMS FSM (future testing needed) -cli history works properly with the add on of an empty line as the last command
2020-07-28 Redesign fsm states to be more granular
    [cli_bms.c, fenice_config.h, main.c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]
2020-07-28 Implement failure callback on fsm
    [fenice_config.h, tim.c]
2020-08-17 Fix llist_export and cli_bms commands
    [cli_bms.c]
2020-10-12 Add current sensor datasheet. add conversion functions
2020-10-12 Squashed 'src/bms/lib/cli/' content from commit b7e91c5
    git-subtree-dir: src/bms/lib/cli
    git-subtree-split: b7e91c57b40ce29309c07daa6774f7f126962436
2020-10-12 Squashed 'src/bms/lib/fsm/' content from commit 499cedf
    git-subtree-dir: src/bms/lib/fsm
    git-subtree-split: 499cedffc142a3d46e6fd5a601440d316a133836
2020-10-12 Squashed 'src/bms/lib/llist/' content from commit d1a6b23
    git-subtree-dir: src/bms/lib/llist
    git-subtree-split: d1a6b235d2c3dc94cdb689981a36475279dba25a
2020-10-12 Squashed 'src/bms/lib/llist/' changes from d1a6b23..8598361
    8598361 Add test, vscode and gitignore
    git-subtree-split: 85983614f83bf77b29686ea322ad3e5081b2c747
    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
2020-10-12 Squashed 'src/bms/lib/llist/' changes from 8598361..2128d24
    2128d24 Merge commit 'e3358cbf7d5c9113ca3be71f4560b0b7805793e1' as 'test/munit'
    e3358cb Squashed 'test/munit/' content from commit fbbdf14
    8243cf0 Remove subtree
    git-subtree-split: 2128d24663c110817d6deedcdd179490cd1ba4ad
    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
2020-10-23 fixed bugs of repo split
    [cellboard_config.h, main.h]
2020-12-02 Handle Si8900 reset pin
2021-04-25 error: fix very bad bugs
    [cli_bms.c]
2021-04-25 pack: refactor voltage management
2021-05-06 can: check instance inside interrupt
2021-05-06 can: glue can to fsm
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2021-05-30 fsm: switch to bidimensional array
2021-05-30 Wire soc to current measurement
2021-06-12 bal: fix threshold parameter
    [cli_bms.c, fenice_config.h]
2021-06-28 Use new FSM library. Handle periodic stuff with timers. Add super_fsm to manage everything. Make errors great again
    [can.c, cli_bms.c, fenice_config.h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]
2021-07-13 cellboard: initial STM32L4 commit. Voltages work
2021-07-16 cellboard: fix temperature measurement. Wire i2c errors to error management
    [cellboard.ioc, main.c, main.h]
2021-07-28 si8900: fix adc readings
2021-09-13 error: rename error_unset, add EEPROM communication error
    [cli_bms.c, pack.c]
2021-09-25 current: implement hall-effect current measurement
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2021-09-25 energy: wire SoC estimation code to new current subsystem
2021-10-05 current: move zero adjust after rolling average
2021-10-09 current: use dma to make measurements
2021-10-11 config: fix spi ref
2021-10-11 current: remove rolling average
2021-10-12 Added current_get_current_from_sensor function and modified actual current_get_current function
2021-10-12 Current: changed sensor parameter type from unsigned to uint8_t for memory reasons (accept values only between 0 and 2)
2021-10-13 Adapted _cli_current to the new current_get_current_from_sensor function
2021-10-13 cli: fixed ESC freezing
    [cli_bms.c, current.c]
2021-10-14 config: add error on write fail
    [cli_bms.c, mainboard.ioc, tim.c]
2021-10-15 eeprom: fix clock polarity. Add write error
    [mainboard.ioc, spi.c]
2021-10-20 can_comm: included bms ids
2021-10-26 swap energy and soc. Improve tests
    [cli_bms.c, main.c]
2021-10-26 pack: split old pack file in current, pack, temperatures and voltages
2021-10-27 config: fixed memory handling
    [main.c]
2021-10-28 can_comms: fixed CAN_WAIT and mailbox
    [can.c, cellboard.ioc, main.c]
2021-10-29 bal_fsm: chanched bal.cells's type to bms_balancing_cells
2021-10-29 can: enabled fifo0 msg pending interrupt
2021-11-03 bal: adapted existing hateville solution to handle bms_balancing_cells array
2021-11-04 can: fixed communication: oscillator issue
    [can.c, main.h, mainboard.ioc]
2021-11-04 can: fixed CAN_WAIT macro
    [main.c]
2021-11-08 voltage: added voltage_set_cells function
2021-11-08 can: update voltages msg handler
2021-11-09 can: fixed CAN_WAIT and voltages send
2021-11-09 can: implemented new bms messages receive
2021-11-10 can: configured filter for bms_balancing
2021-11-11 can: moved filter config from main to can_init_with_filter()
2021-11-11 temperatures: added temperatur_set_cells function
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2021-11-11 bal_fsm: implemented discharge using timers tim: fixed wrong interrupt trigger on startup extra: added .clang-format file
    [cellboard.ioc, cellboard_config.h, main.c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]
2021-11-11 tim: fixed first interrupt callback error
    [tim.c]
2021-11-12 fixed fenice_config.h after merge
    [fenice_config.h]
2021-11-17 bal: fixed fsm and ltc_utils
    [main.c]
2021-11-17 can: fixed storage of voltages and temps
2021-11-18 measures: use of a flag for current and temp measurements
2021-11-18 bal_fsm: use of a timer instead of busy wait
2021-11-25 hw: led off when error on undervoltage or overvoltage
    [fenice_config.h]
2021-12-01 cli_bms: fixed bal test
    [cli_bms.c]
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2021-12-01 imd: fixed reading of tim->ARR register value
    [imd.c]
2021-12-02 proj: now using tim9 as bms timer and tim2 as imd timer
2021-12-02 config: fixed macro declaration
    [mainboard_config.h]
2021-12-02 fixed timers behaviour
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2021-12-06 bal: fixed prev commit issues
    [main.c]
2022-02-24 feedback: working reading values from adc and gpio
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2022-03-16 adapted feedback to new board and updated can messages
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2022-04-06 cellboard: implemented measurements flag as bitset and added ts_status sending message to 200ms timer (with temps)
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2022-04-27 cellboard: fixed balancing discharge
    [bootloader.c, cellboard.ioc, cellboard_config.h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]
2022-04-27 fans_buzzer: added control for fans (and buzzer)
    [fans_buzzer.c, fans_buzzer.h, main.c]
2022-04-27 bms_fsm: fixed fault state exit condition
2022-04-28 added watch cli command and coloured output for "volt all"
2022-05-09 cli: added colours and discharge info to "volt all"; fixed imd; made watch non stopping
    [cli_bms.c, imd.c, main.c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]
2022-05-09 bal: better control on end of discharge and added target voltage
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2022-05-09 fans: fixed fans initial speed
    [fans_buzzer.c]
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2022-06-14 bms_fsm: fixed feedbacks checking
2022-06-16 timebase: switched from measures to timebase and changed the timer functionality
2022-06-16 bms_fsm: fixed precharge trheshold and on state function
    [fenice_config.h]
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2022-08-30 fix: error handling in temps and voltages
2022-08-31 fix: fixed message cells_temp
    [main.c]
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2023-06-06 fix: canlib related fixes
    [can.c, cli_bms.c, fenice_config.h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]
2023-06-08 fix: update latest canlib changes
    [cli_bms.c, fans_buzzer.c, main.c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]
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2023-06-27 fix: feedbacks and adc
    [adc.c, cli_bms.c, feedback.c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]
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2023-06-28 fix: fans pwm
2023-06-28 feat: functions for testing + small fixes
    [cli_bms.c, feedback.c, imd.c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]
2023-06-29 fix: flash via can and errors
    [cli_bms.c, main.h, measures.c]
2023-06-29 fix: wrong voltages readings and conversion
    [cli_bms.c, main.c]
2023-07-01 fix: wrong temperature readings and feedbacks
    [cli_bms.c, feedback.c, fenice_config.h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]
2023-07-02 fix: feedbacks, temperatures and can
    [bootloader.c, cellboard_config.h, feedback.c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]
2023-07-04 fix: current measurement conversion
    [current.c, main.c, measures.c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]
2023-07-04 fix: comment watchdog in fsm for test
    [watchdog.c]
2023-07-04 fix: wrong feedback thresholds
    [feedback.c]
2023-07-05 fix: balancing and wrong temperatures info
2023-07-06 fix: comment out handcart watchdog
    [watchdog.c]
2023-07-06 fix: slow cellboard CAN communication
    [cellboard_config.h, cli_bms.c, fenice_config.h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]
2023-07-06 fix: check precharge pack and bus voltages
    [cli_bms.c, feedback.c, fenice_config.h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]
2023-07-09 fix: disable watchdogs for handcart
    [main.c, watchdog.c]
2023-07-09 fix: feedback threshold for handcart
    [feedback.c]
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2023-07-10 fix: fault after car power on
    [fans_buzzer.c, fans_buzzer.h, main.c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]
2023-07-10 fix: reset timestamp inside while
    [main.c]
2023-07-10 feat: change fans speed based on temperature always
2023-07-11 fix: volt readings and fans speed while balancing
    [cli_bms.c, main.c, measures.c]
2023-07-13 fix: bms fault on power on
    [main.c, measures.c]
2023-07-20 fix: new balancing FSM
    [cellboard.ioc, cellboard_config.h, main.c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]
2023-07-24 fix: shorter air check timeout
    [fenice_config.h]
2023-07-25 fix: send min, max and avg temp and volts one time
2023-07-25 fix: get correct current while charging
    [current.c]
2023-07-26 fix: revert measurement code to previous version
    [cellboard.ioc, main.c, measures.c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]
2023-07-27 fix: wrong timer in autoreload set
2023-08-01 fix: auto fans speed not working after override reset
    [cli_bms.c, fans_buzzer.c, fans_buzzer.h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]
2023-08-09 fix: fans and current connectors disconnection errors
    [current.c]
2023-08-10 fix: current sensors connector errors
    [current.c, feedback.c, measures.c]
2023-08-10 fix: temperature connectors errors
2023-08-11 feat: add less strict temperatures error check
2023-08-16 fix: switch from single to group temp error check
2023-09-28 fix: precharge timeout over 10s
    [fenice_config.h, mainboard.ioc]
2023-09-29 fix: precharge error handling
    [mainboard.ioc]
2023-09-29 fix: battery voltage mismatch error
2023-11-19 fix: power conversion in kW
2023-12-12 feat: set balancing threshold via can and send cell voltage sum and average
2023-12-13 fix: send cell voltages info via can
    [measures.c]
2023-12-13 fix: use sum of cells voltage in voltage mistmatch error check
2024-02-21 fix(current): remove shunt from current measures
    [adc.c, current.c]
2024-02-21 feat(blink): update led blink library to the latest version
2024-02-27 feat(balancing): remove eeprom blocking functions from can interrupt callback
2024-03-01 fix(precharge): increase precharge timeout
    [fenice_config.h, mainboard.ioc]
2024-03-06 feat(error): keep latest expired error
    [feedback.c]
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2024-03-21 fix(debug-signals): set feedback signals only in ts on
    [cli_bms.c, feedback.c]
2024-03-26 feat(errors): implemenet new error library
    [can.c, cli_bms.c, current.c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]
2024-04-06 fix: change check mux feedbacks low threshold
    [feedback.c]
2024-04-11 fix: wrong filter id for cellboard balancing
2024-04-17 feat: update canlib and error-handler versions
    [pack.c]
2024-06-08 fix: change feedback thresholds for handcart
    [feedback.c]
2024-07-12 fix(errors)move error_expire inside the correct timer callback
    [tim.c]
2024-07-15 fix(errors): error expire at random
    [cli_bms.c, current.c, feedback.c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]
2024-08-07 fix(temperatures): fix broken reading temperatures
    [can.c, current.c]
2024-08-07 BREAKING: NEW ERROR LIBRARY
    [cli_bms.c, current.c, feedback.c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]
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2025-06-10 fix: flash cellboard 0 via can
    [main.c]
2026-06-29 fix: update mainboard with new canlib
    [can.c, cli_bms.c, feedback.c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]
2026-07-01 fix: openblt hard fault
    [main.c, measures.c]

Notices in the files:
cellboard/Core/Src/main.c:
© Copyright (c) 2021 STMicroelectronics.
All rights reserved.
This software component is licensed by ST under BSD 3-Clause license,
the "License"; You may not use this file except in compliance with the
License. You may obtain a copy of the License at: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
